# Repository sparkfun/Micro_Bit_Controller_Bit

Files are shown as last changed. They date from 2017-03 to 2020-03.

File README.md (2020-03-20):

SparkFun controller:bit - micro:bit Carrier Board (Qwiic)
========================================

<table class="table table-hover table-striped table-bordered">
  <tr align="center">
   <td><a href="https://www.sparkfun.com/products/16129">SparkFun controller:bit - micro:bit Carrier Board (Qwiic)</a></td>
   <td><a href="https://www.sparkfun.com/products/16403">SparkFun micro:arcade kit for micro:bit v2.0</a></td>
  </tr>
  <tr align="center">
   <td><i>SparkFun controller:bit - micro:bit Carrier Board (Qwiic)<br /> [ <a href="https://www.sparkfun.com/products/16129">DEV-16129</a> ]</i></td>
   <td><i>SparkFun micro:arcade kit for micro:bit v2.0 <br />[ <a href="https://www.sparkfun.com/products/16403">KIT-16403</a> ]</i></td>
  </tr>
</table>

The SparkFun controller:bit is a fun-filled “carrier” board for the micro:bit that, when combined with the micro:bit, provides you with a fully functional game system. Designed in a similar form factor to the classic Nintendo NES controller, the controller:bit is equipped with a four-direction “D-pad” on the left side of the board and two action buttons on the right side of the board. The two push buttons on the micro:bit in the center function as start and select. The back of the board also includes poke-home connectors if you decide to go retro by connecting connect arcade buttons and switches. Check out the micro:arcade kit if you decide to build your very own arcade cabinet using the micro:bit!

Repository Contents
-------------------

* **/Firmware** - Example code 
* **/Hardware** - Eagle design files (.brd, .sch)
* **/Hardware/Production** - Production panel files (.brd)

Documentation
--------------
* **[Library](https://github.com/sparkfun/pxt-gamer-bit)** - PXT controller:bit firmware
* **[Micro:Arcade Kit Experiment Guide](https://learn.sparkfun.com/tutorials/microarcade-kit-experiment-guide/)** -  Experiment guide using the controller:bit carrier board.
* **[Wireless Remote Control with micro:bit](https://learn.sparkfun.com/tutorials/wireless-remote-control-with-microbit)** - Project guide using the micro:bot and micro:arcade kits. By utilizing the radio blocks, you can wirelessly control the micro:bot using the controller:bit.

Version History
---------------

* [SparkFun controller:bit - micro:bit Carrier Board (Qwiic)](https://www.sparkfun.com/products/16129) - Latest and greatest (has qwiic connector)
* [SparkFun gamer:bit](https://www.sparkfun.com/products/14215) - Initial product (no qwiic connector)

Product Versions
----------------

* [KIT-16403](https://www.sparkfun.com/products/16403) - Kit with the controller:bit
* [DEV-16129](https://www.sparkfun.com/products/16129) - V21, revision and renamed as controller:bit
* [KIT-14218](https://www.sparkfun.com/products/14218) - Kit with the gamer:bit
* [DEV-14215](https://www.sparkfun.com/products/14215) - v10, Initial release as the gamer:bit

License Information
-------------------

This product is _**open source**_! 

Please review the LICENSE.md file for license information. 

If you have any questions or concerns on licensing, please contact technical support on our [SparkFun forums](https://forum.sparkfun.com/viewforum.php?f=152).

Distributed as-is; no warranty is given.

- Your friends at SparkFun.

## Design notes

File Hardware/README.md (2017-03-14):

SparkFun <PRODUCT NAME> Design Files
=====================================

The .sch and .brd files hare are Eagle CAD schematic and PCB design files from SparkFun Electronics.
A freeware version of Eagle can be found [here](http://www.cadsoftusa.com/download-eagle/freeware/).

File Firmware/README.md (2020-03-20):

SparkFun Controller:Bit Firmware
===================================

* **/Examples**
    * _/Hardware Test_ - Python example to test the controller:bit
    * _/micro_arcade Kit Experiment Guide_ - Example code used in the micro:bot Kit Experiment Guide. While they are compiled HEX codes, you can modify the example code once they are imported into MakeCode editor.
    * _/Wireless Remote Control with micro_bit_ - Example code used in the Wireless Remote Control with micro:bit tutorial. While they are compiled HEX codes, you can modify the example code once they are imported into MakeCode editor.

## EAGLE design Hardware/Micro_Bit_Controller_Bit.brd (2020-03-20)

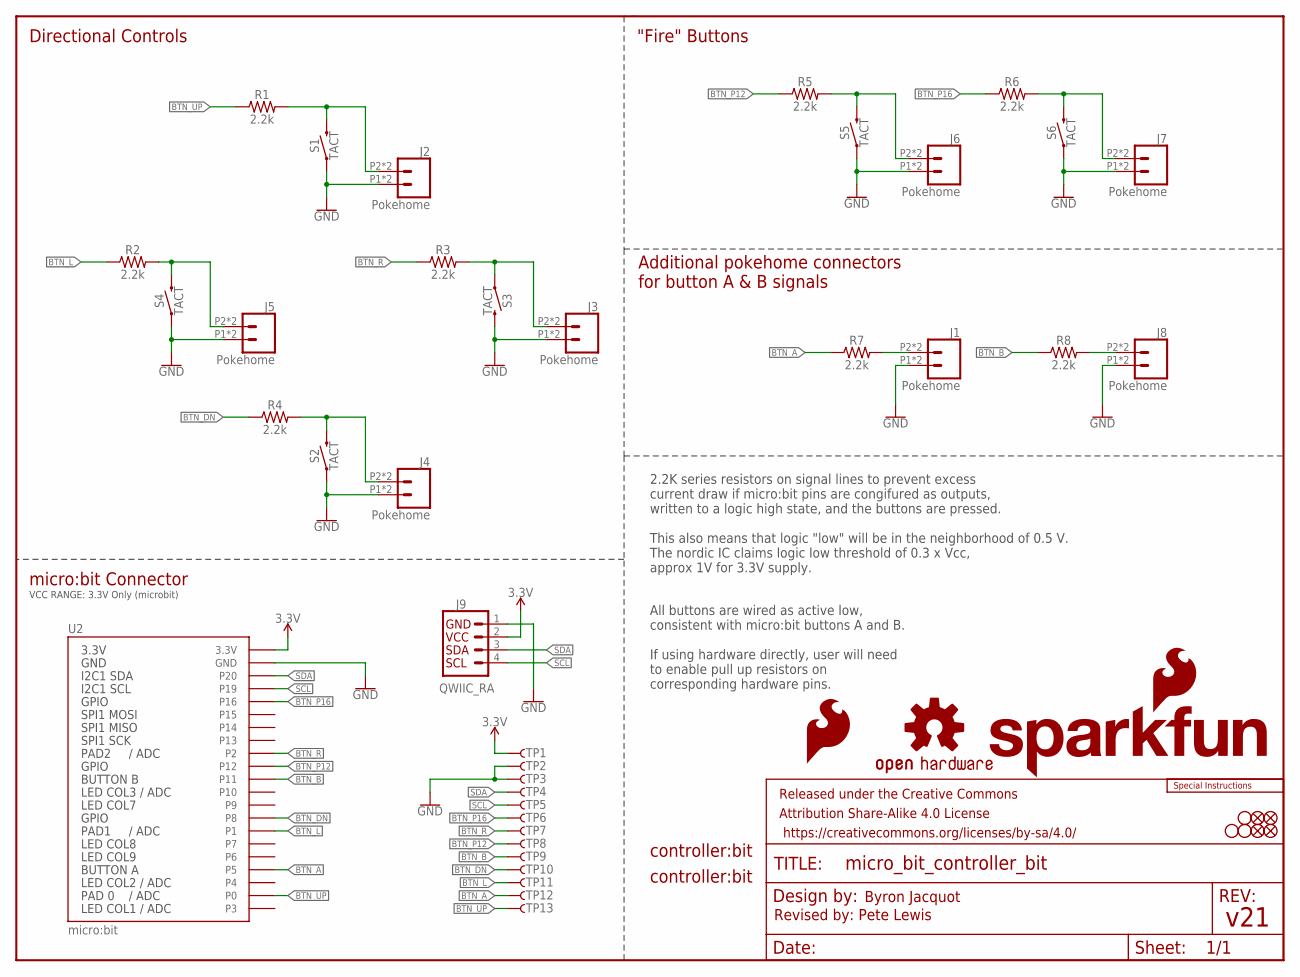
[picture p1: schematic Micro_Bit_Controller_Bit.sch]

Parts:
FD1, FD2, FD3, FD4: FIDUCIALUFIDUCIAL; FIDUCIAL-MICRO
FRAME1: FRAME-LETTER; CREATIVE_COMMONS
H1, H2, H3: STAND-OFF
J1, J2, J3, J4, J5, J6, J7, J8: Pokehome; 1X02_POKEHOME
J9: QWIIC_RA; JST04_1MM_RA
LOGO1: SFE_LOGO_FLAME.2_INCH; SFE_LOGO_FLAME_.2
LOGO2: OSHW-LOGOL; OSHW-LOGO-L
LOGO3: SFE_LOGO_NAME_FLAME.3_INCH; SFE_LOGO_NAME_FLAME_.3
R1, R2, R3, R4, R5, R6, R7, R8: 2.2k; 0603
S1, S2, S3, S4, S5, S6: TACT; TACTILE_SWITCH_SMD_12MM
TP1, TP2, TP3, TP4, TP5, TP6, TP7, TP8, TP9, TP10, TP11, TP12, TP13: TEST-POINT3X5; PAD.03X.05
U2: micro:bit; MICRO:BIT-RA_SMD
U$1: SPECIAL_INSTRUCTIONS-ORDERING; ORDERING_INSTRUCTIONS
U$3, U$6: LOGO-CONTROLLER_BIT

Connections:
3.3V: J9.2, TP1.P$1, U2.P$27 (3.3V), U2.P$28 (3.3V), U2.P$29 (3.3V), U2.P$30 (3.3V), U2.P$31 (3.3V), U2.P$32 (3.3V)
BTN_A: R7.1, TP12.P$1, U2.P$7 (P5)
BTN_B: R8.1, TP9.P$1, U2.P$17 (P11)
BTN_DN: R4.1, TP10.P$1, U2.P$14 (P8)
BTN_L: R2.1, TP11.P$1, U2.P$10 (P1), U2.P$11 (P1), U2.P$12 (P1), U2.P$13 (P1)
BTN_P12: R5.1, TP8.P$1, U2.P$18 (P12)
BTN_P16: R6.1, TP6.P$1, U2.P$26 (P16)
BTN_R: R3.1, TP7.P$1, U2.P$19 (P2), U2.P$20 (P2), U2.P$21 (P2), U2.P$22 (P2)
BTN_UP: R1.1, TP13.P$1, U2.P$2 (P0), U2.P$3 (P0), U2.P$4 (P0), U2.P$5 (P0)
GND: J1.P1 (1), J1.P3 (1), J2.P1 (1), J2.P3 (1), J3.P1 (1), J3.P3 (1), J4.P1 (1), J4.P3 (1), J5.P1 (1), J5.P3 (1), J6.P1 (1), J6.P3 (1), J7.P1 (1), J7.P3 (1), J8.P1 (1), J8.P3 (1), J9.1, S1.1, S2.1, S3.3 (2), S4.1, S5.1, S6.1, TP2.P$1, TP3.P$1, U2.P$35 (GND), U2.P$36 (GND), U2.P$37 (GND), U2.P$38 (GND), U2.P$39 (GND), U2.P$40 (GND)
unnamed: J2.P2 (2), J2.P4 (2), R1.2, S1.3 (2)
unnamed: J5.P2 (2), J5.P4 (2), R2.2, S4.3 (2)
unnamed: J4.P2 (2), J4.P4 (2), R4.2, S2.3 (2)
unnamed: J3.P2 (2), J3.P4 (2), R3.2, S3.1
unnamed: J7.P2 (2), J7.P4 (2), R6.2, S6.3 (2)
unnamed: J8.P2 (2), J8.P4 (2), R8.2
unnamed: J1.P2 (2), J1.P4 (2), R7.2
unnamed: J6.P2 (2), J6.P4 (2), R5.2, S5.3 (2)
SCL: J9.4, TP5.P$1, U2.P$33 (P19)
SDA: J9.3, TP4.P$1, U2.P$34 (P20)

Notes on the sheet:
Byron Jacquot
v21
All buttons are wired as active low, consistent with micro:bit buttons A and B. If using hardware directly, user will need to enable pull up resistors on corresponding hardware pins.
2.2K series resistors on signal lines to prevent excess current draw if micro:bit pins are congifured as outputs, written to a logic high state, and the buttons are pressed. This also means that logic "low" will be in the neighborhood of 0.5 V. The nordic IC claims logic low threshold of 0.3 x Vcc,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
Additional pokehome connectors for button A & B signals
Directional Controls
"Fire" Buttons
micro:bit Connector
Revised by: Pete Lewis
VCC RANGE: 3.3V Only (microbit)

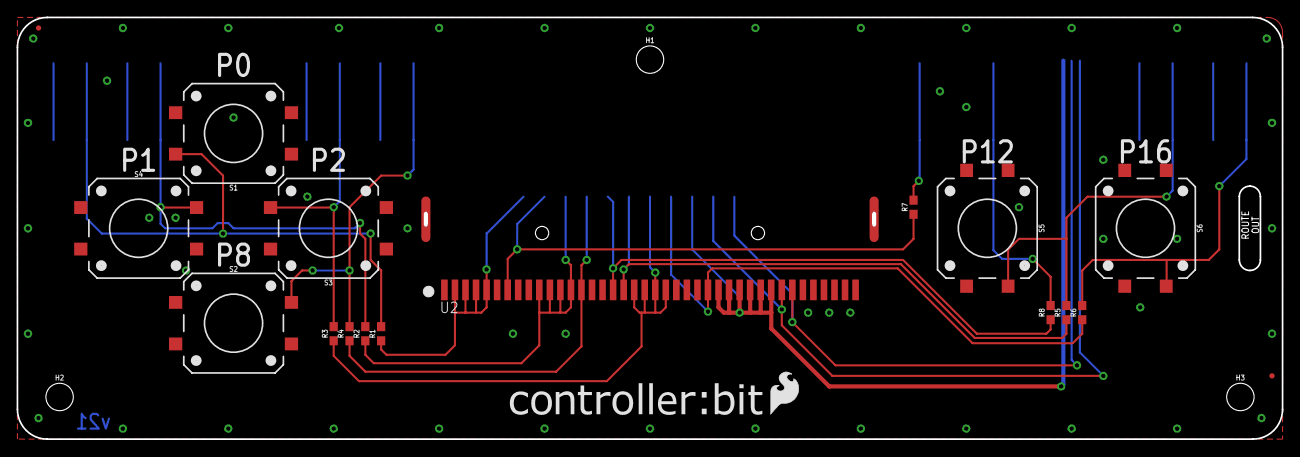
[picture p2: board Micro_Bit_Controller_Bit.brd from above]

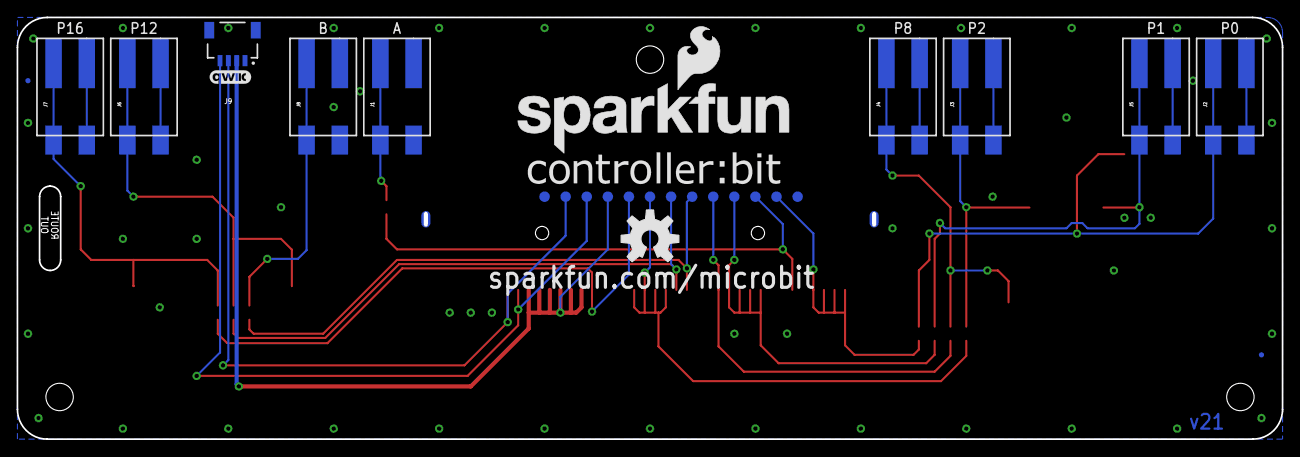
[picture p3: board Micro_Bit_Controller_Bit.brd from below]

Board: 2 copper layers, 152.4 x 50.8 mm, 52 parts (28 on the bottom side), 20 nets.

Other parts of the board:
U$2: QWIIC_5MM

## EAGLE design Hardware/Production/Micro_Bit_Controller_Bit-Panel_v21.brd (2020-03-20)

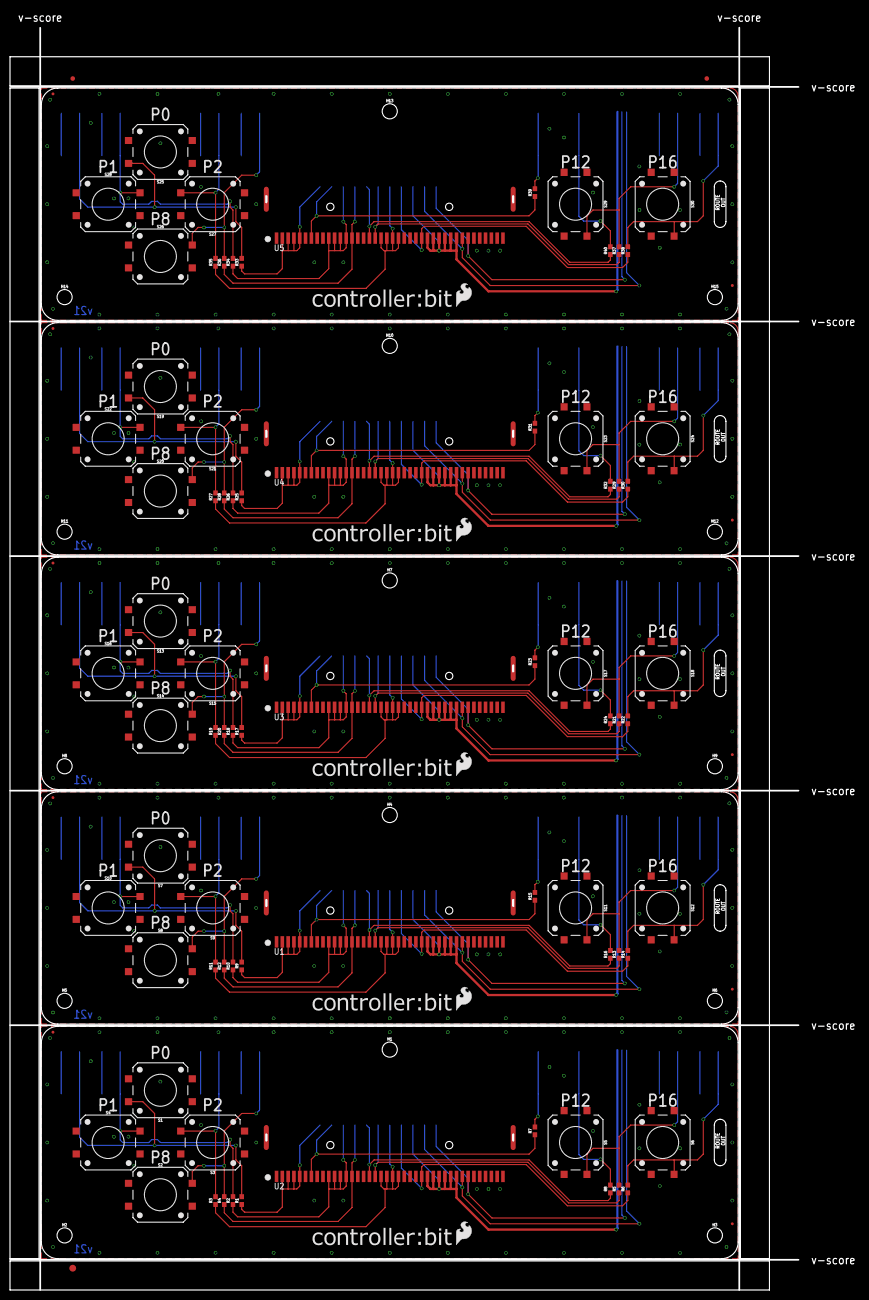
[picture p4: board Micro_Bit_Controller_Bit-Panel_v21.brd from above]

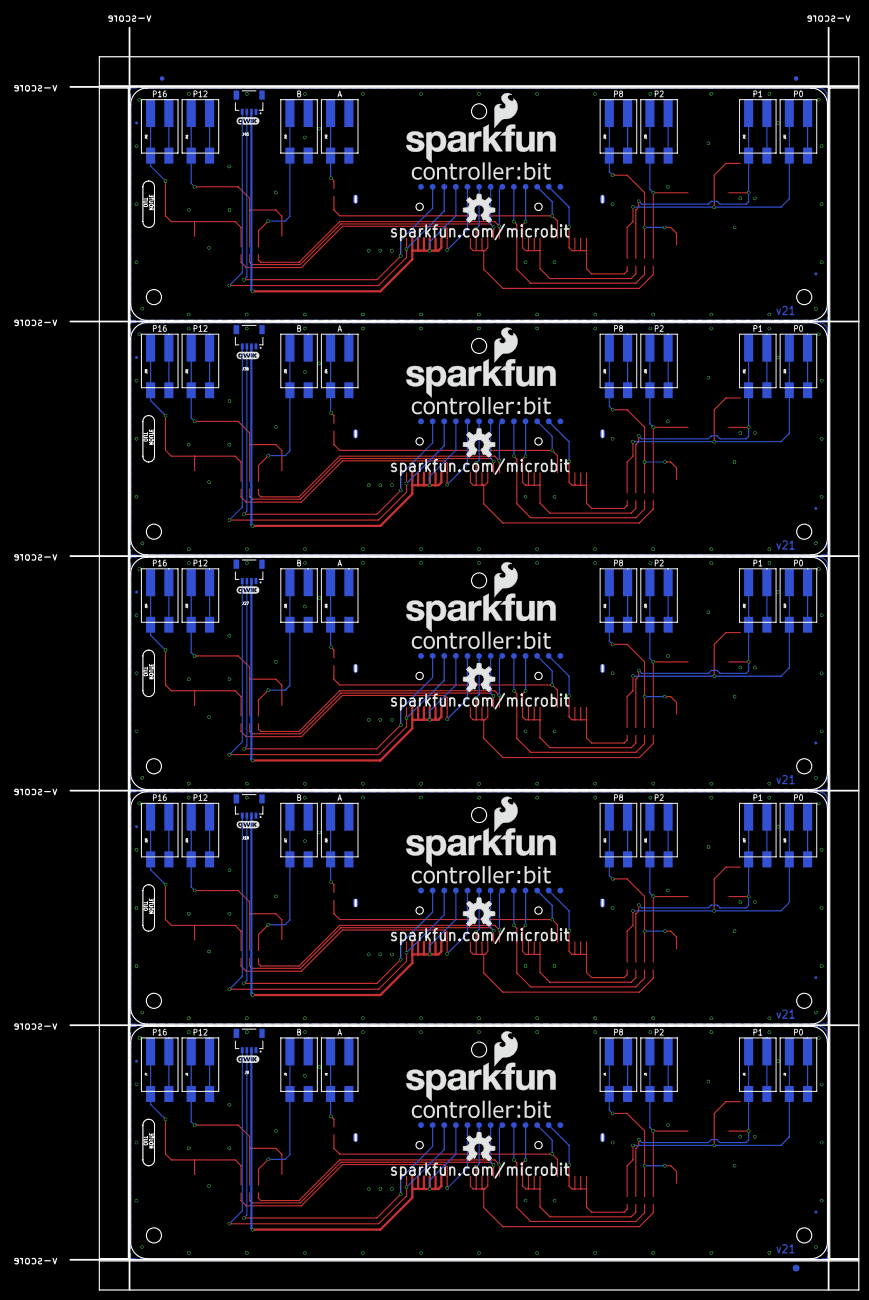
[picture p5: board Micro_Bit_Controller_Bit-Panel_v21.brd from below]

Board: 2 copper layers, 172.5 x 276.1 mm, 256 parts (143 on the bottom side), 100 nets.

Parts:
E$1, E$2, E$3, E$4: FIDUCIAL-1X2
E$5, E$6: FIDUCIAL-1.5X3
FD1, FD2, FD3, FD4, FD5, FD6, FD7, FD8, FD9, FD10, FD11, FD12, FD13, FD14, FD15, FD16, FD17, FD18, FD19, FD20: FIDUCIALUFIDUCIAL; FIDUCIAL-MICRO
H1, H2, H3, H4, H5, H6, H7, H8, H9, H10, H11, H12, H13, H14, H15: STAND-OFF
J1, J2, J3, J4, J5, J6, J7, J8, J10, J11, J12, J13, J14, J15, J16, J17, J19, J20, J21, J22, J23, J24, J25, J26, J28, J29, J30, J31, J32, J33, J34, J35, J37, J38, J39, J40, J41, J42, J43, J44: Pokehome; 1X02_POKEHOME
J9, J18, J27, J36, J45: QWIIC_RA; JST04_1MM_RA
LOGO1, LOGO4, LOGO7, LOGO10, LOGO13: SFE_LOGO_FLAME.2_INCH; SFE_LOGO_FLAME_.2
LOGO2, LOGO5, LOGO8, LOGO11, LOGO14: OSHW-LOGOL; OSHW-LOGO-L
LOGO3, LOGO6, LOGO9, LOGO12, LOGO15: SFE_LOGO_NAME_FLAME.3_INCH; SFE_LOGO_NAME_FLAME_.3
R1, R2, R3, R4, R5, R6, R7, R8, R9, R10, R11, R12, R13, R14, R15, R16, R17, R18, R19, R20, R21, R22, R23, R24, R25, R26, R27, R28, R29, R30, R31, R32, R33, R34, R35, R36, R37, R38, R39, R40: 2.2k; 0603
S1, S2, S3, S4, S5, S6, S7, S8, S9, S10, S11, S12, S13, S14, S15, S16, S17, S18, S19, S20, S21, S22, S23, S24, S25, S26, S27, S28, S29, S30: TACT; TACTILE_SWITCH_SMD_12MM
TP1, TP2, TP3, TP4, TP5, TP6, TP7, TP8, TP9, TP10, TP11, TP12, TP13, TP14, TP15, TP16, TP17, TP18, TP19, TP20, TP21, TP22, TP23, TP24, TP25, TP26, TP27, TP28, TP29, TP30, TP31, TP32, TP33, TP34, TP35, TP36, TP37, TP38, TP39, TP40, TP41, TP42, TP43, TP44, TP45, TP46, TP47, TP48, TP49, TP50, TP51, TP52, TP53, TP54, TP55, TP56, TP57, TP58, TP59, TP60, TP61, TP62, TP63, TP64, TP65: TEST-POINT3X5; PAD.03X.05
U1, U2, U3, U4, U5: micro:bit; MICRO:BIT-RA_SMD
U$1, U$2, U$7, U$10, U$13: QWIIC_5MM
U$3, U$4, U$5, U$6, U$8, U$9, U$11, U$12, U$14, U$15: LOGO-CONTROLLER_BIT

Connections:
3.3V: J9.2, TP1.P$1, U2.P$27, U2.P$28, U2.P$29, U2.P$30, U2.P$31, U2.P$32
3.3V1: J18.2, TP14.P$1, U1.P$27, U1.P$28, U1.P$29, U1.P$30, U1.P$31, U1.P$32
3.3V2: J27.2, TP27.P$1, U3.P$27, U3.P$28, U3.P$29, U3.P$30, U3.P$31, U3.P$32
3.3V3: J36.2, TP40.P$1, U4.P$27, U4.P$28, U4.P$29, U4.P$30, U4.P$31, U4.P$32
3.3V4: J45.2, TP53.P$1, U5.P$27, U5.P$28, U5.P$29, U5.P$30, U5.P$31, U5.P$32
BTN_A: R7.1, TP12.P$1, U2.P$7
BTN_A1: R15.1, TP25.P$1, U1.P$7
BTN_A2: R23.1, TP38.P$1, U3.P$7
BTN_A3: R31.1, TP51.P$1, U4.P$7
BTN_A4: R39.1, TP64.P$1, U5.P$7
BTN_B: R8.1, TP9.P$1, U2.P$17
BTN_B1: R16.1, TP22.P$1, U1.P$17
BTN_B2: R24.1, TP35.P$1, U3.P$17
BTN_B3: R32.1, TP48.P$1, U4.P$17
BTN_B4: R40.1, TP61.P$1, U5.P$17
BTN_DN: R4.1, TP10.P$1, U2.P$14
BTN_DN1: R12.1, TP23.P$1, U1.P$14
BTN_DN2: R20.1, TP36.P$1, U3.P$14
BTN_DN3: R28.1, TP49.P$1, U4.P$14
BTN_DN4: R36.1, TP62.P$1, U5.P$14
BTN_L: R2.1, TP11.P$1, U2.P$10, U2.P$11, U2.P$12, U2.P$13
BTN_L1: R10.1, TP24.P$1, U1.P$10, U1.P$11, U1.P$12, U1.P$13
BTN_L2: R18.1, TP37.P$1, U3.P$10, U3.P$11, U3.P$12, U3.P$13
BTN_L3: R26.1, TP50.P$1, U4.P$10, U4.P$11, U4.P$12, U4.P$13
BTN_L4: R34.1, TP63.P$1, U5.P$10, U5.P$11, U5.P$12, U5.P$13
BTN_P1: R14.1, TP19.P$1, U1.P$26
BTN_P2: R13.1, TP21.P$1, U1.P$18
BTN_P3: R22.1, TP32.P$1, U3.P$26
BTN_P4: R21.1, TP34.P$1, U3.P$18
BTN_P5: R30.1, TP45.P$1, U4.P$26
BTN_P6: R29.1, TP47.P$1, U4.P$18
BTN_P7: R38.1, TP58.P$1, U5.P$26
BTN_P8: R37.1, TP60.P$1, U5.P$18
BTN_P12: R5.1, TP8.P$1, U2.P$18
BTN_P16: R6.1, TP6.P$1, U2.P$26
BTN_R: R3.1, TP7.P$1, U2.P$19, U2.P$20, U2.P$21, U2.P$22
BTN_R1: R11.1, TP20.P$1, U1.P$19, U1.P$20, U1.P$21, U1.P$22
BTN_R2: R19.1, TP33.P$1, U3.P$19, U3.P$20, U3.P$21, U3.P$22
BTN_R3: R27.1, TP46.P$1, U4.P$19, U4.P$20, U4.P$21, U4.P$22
BTN_R4: R35.1, TP59.P$1, U5.P$19, U5.P$20, U5.P$21, U5.P$22
BTN_UP: R1.1, TP13.P$1, U2.P$2, U2.P$3, U2.P$4, U2.P$5
BTN_UP1: R9.1, TP26.P$1, U1.P$2, U1.P$3, U1.P$4, U1.P$5
BTN_UP2: R17.1, TP39.P$1, U3.P$2, U3.P$3, U3.P$4, U3.P$5
BTN_UP3: R25.1, TP52.P$1, U4.P$2, U4.P$3, U4.P$4, U4.P$5
BTN_UP4: R33.1, TP65.P$1, U5.P$2, U5.P$3, U5.P$4, U5.P$5
GND: J1.P1, J1.P3, J2.P1, J2.P3, J3.P1, J3.P3, J4.P1, J4.P3, J5.P1, J5.P3, J6.P1, J6.P3, J7.P1, J7.P3, J8.P1, J8.P3, J9.1, S1.1, S2.1, S3.3, S4.1, S5.1, S6.1, TP2.P$1, TP3.P$1, U2.P$35, U2.P$36, U2.P$37, U2.P$38, U2.P$39, U2.P$40
GND1: J10.P1, J10.P3, J11.P1, J11.P3, J12.P1, J12.P3, J13.P1, J13.P3, J14.P1, J14.P3, J15.P1, J15.P3, J16.P1, J16.P3, J17.P1, J17.P3, J18.1, S7.1, S8.1, S9.3, S10.1, S11.1, S12.1, TP15.P$1, TP16.P$1, U1.P$35, U1.P$36, U1.P$37, U1.P$38, U1.P$39, U1.P$40
GND2: J19.P1, J19.P3, J20.P1, J20.P3, J21.P1, J21.P3, J22.P1, J22.P3, J23.P1, J23.P3, J24.P1, J24.P3, J25.P1, J25.P3, J26.P1, J26.P3, J27.1, S13.1, S14.1, S15.3, S16.1, S17.1, S18.1, TP28.P$1, TP29.P$1, U3.P$35, U3.P$36, U3.P$37, U3.P$38, U3.P$39, U3.P$40
GND3: J28.P1, J28.P3, J29.P1, J29.P3, J30.P1, J30.P3, J31.P1, J31.P3, J32.P1, J32.P3, J33.P1, J33.P3, J34.P1, J34.P3, J35.P1, J35.P3, J36.1, S19.1, S20.1, S21.3, S22.1, S23.1, S24.1, TP41.P$1, TP42.P$1, U4.P$35, U4.P$36, U4.P$37, U4.P$38, U4.P$39, U4.P$40
GND4: J37.P1, J37.P3, J38.P1, J38.P3, J39.P1, J39.P3, J40.P1, J40.P3, J41.P1, J41.P3, J42.P1, J42.P3, J43.P1, J43.P3, J44.P1, J44.P3, J45.1, S25.1, S26.1, S27.3, S28.1, S29.1, S30.1, TP54.P$1, TP55.P$1, U5.P$35, U5.P$36, U5.P$37, U5.P$38, U5.P$39, U5.P$40
unnamed: J2.P2, J2.P4, R1.2, S1.3
unnamed: J5.P2, J5.P4, R2.2, S4.3
unnamed: J4.P2, J4.P4, R4.2, S2.3
unnamed: J3.P2, J3.P4, R3.2, S3.1
unnamed: J7.P2, J7.P4, R6.2, S6.3
unnamed: J8.P2, J8.P4, R8.2
unnamed: J1.P2, J1.P4, R7.2
unnamed: J10.P2, J10.P4, R9.2, S7.3
unnamed: J13.P2, J13.P4, R10.2, S10.3
unnamed: J12.P2, J12.P4, R12.2, S8.3
unnamed: J11.P2, J11.P4, R11.2, S9.1
unnamed: J14.P2, J14.P4, R13.2, S11.3
unnamed: J15.P2, J15.P4, R14.2, S12.3
unnamed: J16.P2, J16.P4, R15.2
unnamed: J17.P2, J17.P4, R16.2
unnamed: J19.P2, J19.P4, R17.2, S13.3
unnamed: J22.P2, J22.P4, R18.2, S16.3
unnamed: J21.P2, J21.P4, R20.2, S14.3
unnamed: J20.P2, J20.P4, R19.2, S15.1
unnamed: J23.P2, J23.P4, R21.2, S17.3
unnamed: J24.P2, J24.P4, R22.2, S18.3
unnamed: J25.P2, J25.P4, R23.2
unnamed: J26.P2, J26.P4, R24.2
unnamed: J28.P2, J28.P4, R25.2, S19.3
unnamed: J31.P2, J31.P4, R26.2, S22.3
unnamed: J30.P2, J30.P4, R28.2, S20.3
unnamed: J29.P2, J29.P4, R27.2, S21.1
unnamed: J32.P2, J32.P4, R29.2, S23.3
unnamed: J33.P2, J33.P4, R30.2, S24.3
unnamed: J34.P2, J34.P4, R31.2
unnamed: J35.P2, J35.P4, R32.2
unnamed: J37.P2, J37.P4, R33.2, S25.3
unnamed: J40.P2, J40.P4, R34.2, S28.3
unnamed: J39.P2, J39.P4, R36.2, S26.3
unnamed: J38.P2, J38.P4, R35.2, S27.1
unnamed: J41.P2, J41.P4, R37.2, S29.3
unnamed: J42.P2, J42.P4, R38.2, S30.3
unnamed: J43.P2, J43.P4, R39.2
unnamed: J44.P2, J44.P4, R40.2
unnamed: J6.P2, J6.P4, R5.2, S5.3
SCL: J9.4, TP5.P$1, U2.P$33
SCL1: J18.4, TP18.P$1, U1.P$33
SCL2: J27.4, TP31.P$1, U3.P$33
SCL3: J36.4, TP44.P$1, U4.P$33
SCL4: J45.4, TP57.P$1, U5.P$33
SDA: J9.3, TP4.P$1, U2.P$34
SDA1: J18.3, TP17.P$1, U1.P$34
SDA2: J27.3, TP30.P$1, U3.P$34
SDA3: J36.3, TP43.P$1, U4.P$34
SDA4: J45.3, TP56.P$1, U5.P$34

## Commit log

2017-03-14 Initial boilerplate checkin.
    Also added a library with the 80 pin edge connector in it.
2017-03-15 Library updates & draft of board.
    [Micro_Bit_Gamer_Bit.brd, Micro_Bit_Gamer_Bit.sch]
2017-03-16 Adding pokehome connectors & a little test code
    [Micro_Bit_Gamer_Bit.brd, Micro_Bit_Gamer_Bit.sch]
2017-03-28 Board routed, ready for review.
    [Micro_Bit_Gamer_Bit.brd, Micro_Bit_Gamer_Bit.sch]
2017-03-30 Updates after review.
    See review minutes attached to bug for details.
    [Micro_Bit_Gamer_Bit.brd, Micro_Bit_Gamer_Bit.sch]
2017-04-03 Engineering checklist touchups.
    [Micro_Bit_Gamer_Bit.brd]
2017-04-05 Adjusting silk on directional buttons, as per checklist.
    [Micro_Bit_Gamer_Bit.brd]
2017-04-11 Incorporating Edu Feedback.
    Pokehomes on back of board.
    Touched up logos & markings.
    [Micro_Bit_Gamer_Bit.brd, Micro_Bit_Gamer_Bit.sch]
2017-04-18 Changed name font to match other microbit boards
    [Micro_Bit_Gamer_Bit.brd, Micro_Bit_Gamer_Bit.sch]
2017-05-16 Moved right two buttons together by 0.3 inches
    [Micro_Bit_Gamer_Bit.brd, Micro_Bit_Gamer_Bit.sch]
2017-05-24 Created version 1.0
    [Micro_Bit_Gamer_Bit.brd, Micro_Bit_Gamer_Bit.sch]
2017-05-25 created panel v10
    [Micro_Bit_Gamer_Bit_Panel_v10.brd]
2019-01-21 Add Wireless Remote Control with micro:bit examples
2019-12-09 Moved to SMD connector
    [Micro_Bit_Gamer_Bit.brd, Micro_Bit_Gamer_Bit.sch]
2019-12-09 Update silk to control bit
    On both front and back.
    [Micro_Bit_Gamer_Bit.brd, Micro_Bit_Gamer_Bit.sch]
2019-12-09 Cleaned up a coulpe traces added vias for pour
    [Micro_Bit_Gamer_Bit.brd]
2019-12-10 Added qwiic connector to back side
    [Micro_Bit_Gamer_Bit.brd, Micro_Bit_Gamer_Bit.sch]
2019-12-10 renaming eagle files to match new product name
    [Micro_Bit_Control_Bit.brd, Micro_Bit_Control_Bit.sch]
2019-12-11 Updated contro bit text silk to match other boards
    [Micro_Bit_Control_Bit.brd, Micro_Bit_Control_Bit.sch]
2019-12-11 Adding test points
    [Micro_Bit_Control_Bit.brd, Micro_Bit_Control_Bit.sch]
2019-12-11 vector fonts in sch
    [Micro_Bit_Control_Bit.sch]
2019-12-11 library thing - control bit text device now in SFE aethetics
    [Micro_Bit_Control_Bit.brd, Micro_Bit_Control_Bit.sch]
2019-12-11 sch cleanup and vcc range
    [Micro_Bit_Control_Bit.sch]
2019-12-11 bumped test ppoints to larger size
    also rearragned VCC pin over so it wasn't right next to GND, to help avoid accidental jumpers between VCC and GND.
    [Micro_Bit_Control_Bit.brd, Micro_Bit_Control_Bit.sch]
2019-12-11 production panel files
    [Micro_Bit_Control_Bit-Panel.brd]
2019-12-12 corrected panel to 1x5
    previsously it was 1x6, so we wanted to keep it the same as before and good for pnp machines.
    [Micro_Bit_Control_Bit-Panel.brd]
2019-12-13 removed old/bad production files and update readme
    [Micro_Bit_Control_Bit-Panel.brd, Micro_Bit_Gamer_Bit_Panel_v10.brd]
2019-12-13 Update to correct file name
    no changes to design, just file name
    [Micro_Bit_Controller_Bit.brd, Micro_Bit_Controller_Bit.sch]
2019-12-13 Control:bit logo to Controller:bit
    Also bumped version to v21 in brd and sch, to ensure correct panel files are used.
    [Micro_Bit_Controller_Bit.brd, Micro_Bit_Controller_Bit.sch]
2019-12-13 Production panel v21 (array 1x5)
    [Micro_Bit_Controller_Bit-Panel_v21.brd]
2019-12-16 Schematic cleanup
    -removed pesky test point values (overlap)
    [Micro_Bit_Controller_Bit.brd, Micro_Bit_Controller_Bit.sch]

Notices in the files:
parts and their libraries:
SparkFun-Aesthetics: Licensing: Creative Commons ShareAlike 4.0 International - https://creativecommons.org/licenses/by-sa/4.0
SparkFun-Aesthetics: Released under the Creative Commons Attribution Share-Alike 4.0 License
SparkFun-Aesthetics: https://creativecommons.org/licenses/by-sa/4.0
